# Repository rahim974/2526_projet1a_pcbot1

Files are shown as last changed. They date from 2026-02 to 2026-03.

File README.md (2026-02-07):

# 2526_projet1a_pcbot1
[toc]

## Memo git

Pensez à ajouter votre clé ssh à votre compte github.

### Récupérer le projet

```bash
git clone git@github.com:rahim974/2526_projet1a_pcbot1.git
```

### Récupérer la dernière version

```bash
git pull
```

### Vérifier vos modifications

```bash
git status
```

### Pousser vos modifications

```bash
git add .   # À la place du ".", on peut mettre le chemin des fichiers à ajouter
git commit -m "Message (pour indiquer la mise à jour faite)"
git push
```

# 2/02/2026

## Rôle du robot 

Le robot donne ses coordonnées et ce qu'il y a devant lui (distances aux obstacles). Il doit envoyer son angle d'inclinaison, sa vitesse, son accélération, sa position, à une base.

## Cahier des charges

- Robot doit rouler 
- Connaitre son environnement (distances aux obstacles) 
- Connaitre sa vitesse et sa position
- Pouvoir le charger à une prise 
- Communiquer en continu via le module nrF24L01
- Communiquer avec une station de base (angle, distance)

## Matériels

- Capteur TOF (repérer ce qu'il y a devant)
- nRF24N https://passionelectronique.fr/tutorial-nrf24l01/
- Batterie 18650 Samsung (en USB) https://www.nkon.nl/fr/samsung-inr18650-35e-3400mah-8a.html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
- Moteur continue https://www.gotronic.fr/art-motoreducteur-maqueen-v5-48529.htm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
- Leds 
- Bouton d'alimentation
- Prise secteur https://www.ti.com/lit/ds/symlink/bq25896.pdf?ts=1769962316849
- accéléromètre https://www.st.com/en/mems-and-sensors/lsm6dsox.html
- drivers moteur https://www.ti.com/lit/ds/symlink/drv8411a.pdf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
Ne pas utiliser des librairies déjà existantes sauf si très ressemblant.

## Rôles 

- Schéma architectural sur draw.io 
- Essais capteur TOF

Essais capteur TOF 

I2C entre moteur et accélérateur, driver de batterie

Outil : draw.io

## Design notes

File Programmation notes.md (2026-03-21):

# Fonctionnalités à coder

### 1. Communication et Capteurs (I2C)

- **Driver Capteur TOF (Distance) :** Implémenter le protocole I2C pour lire les distances et repérer les obstacles devant le robot.
- **Driver Accéléromètre (LSM6DSOX) :** Configurer les registres pour récupérer l'accélération et l'inclinaison (angle) afin de connaître la position du robot.
- **Gestion de la Batterie (BQ25896) :** Lire l'état de charge de la batterie Samsung 18650 via I2C pour savoir quand retourner à la prise.

### 2. Propulsion et Mouvement (PWM)

- **Contrôle du DRV8411A :** Générer des signaux PWM pour contrôler la vitesse des moteurs à courant continu.
- **Logique de Direction :** Coder les fonctions de base : `avancer()`, `reculer()`, `tourner_gauche()`, `tourner_droite()` et `stop()`.

### 3. Communication Radio (SPI)

- **Driver nRF24L01 :** Configurer l'interface SPI pour envoyer et recevoir des données en continu.
- **Protocole Station de Base :** Créer une structure de message pour envoyer les coordonnées (angle, distance) à la station de base.

### 4. Interface et Feedback

- **Gestion des LEDs :** Coder les états visuels (ex: clignotement en cas de batterie faible ou obstacle proche).
- **Lecture du Bouton :** Gérer l'anti-rebond (debouncing) pour le bouton d'alimentation ou de démarrage.

### 5. Algorithme Principal (Boucle de contrôle)

- **Évitement d'obstacles :** Fusionner les données du TOF et des moteurs pour s'arrêter avant une collision.
- **Calcul de position :** Utiliser les données de l'accéléromètre pour estimer le déplacement du robot.

# Fonctions déjà existantes à utiliser 

## 1. Pour les Moteurs (Timer & PWM)

Le fichier de référence est `stm32g4xx_hal_tim.h`.

- **`HAL_TIM_PWM_Start(&htimx, TIM_CHANNEL_y)`** :
  - **Rôle** : Allume physiquement le signal PWM sur la broche du moteur.
  - **Utilisation** : À appeler une seule fois dans l'initialisation pour chaque moteur.
- **`__HAL_TIM_SET_COMPARE(&htimx, TIM_CHANNEL_y, valeur)`** :
  - **Rôle** : C'est la fonction la plus importante. Elle change la **vitesse** en modifiant le registre de comparaison (CCR).
  - **Note** : Ce n'est pas une fonction classique mais une "macro" ultra-rapide.

## 2. Pour les Capteurs (I2C)

Le fichier de référence est `stm32g4xx_hal_i2c.h`. Pour ton capteur TOF et le LSM6DSOX, on utilise souvent le mode "Mem" (Mémoire) car ces capteurs fonctionnent avec des registres internes.

- **`HAL_I2C_Mem_Write(...)`** :
  - **Rôle** : Écrit une configuration dans le capteur (ex: allumer le laser du TOF).
- **`HAL_I2C_Mem_Read(...)`** :
  - **Rôle** : Lit une donnée précise (ex: lire les 2 octets de la distance mesurée).

| **Paramètre** | **Signification** | **Exemple (LSM6DSOX)** |
| --- | --- | --- |
| `&hi2c1` | Le bus utilisé | I2C numéro 1 |
| `DevAddress`  | Adresse du composant | `0x6B << 1` (Toujours décaler d'un bit) |
| `MemAddress`  | Registre interne | `0x22` (Donnée Gyro) |
| `pData` | Variable de stockage | Tableau d'octets |

## 3. Pour la Radio nRF24L01 (SPI)

Le fichier de référence est `stm32g4xx_hal_spi.h`.

- **`HAL_SPI_Transmit(&hspix, pData, Size, Timeout)`** :
  - **Rôle** : Envoie un paquet de données vers la station de base via le module radio.
- **`HAL_GPIO_WritePin(GPIOx, GPIO_Pin, PinState)`** :
  - **Rôle** : Très important pour le SPI ! Sert à activer/désactiver la broche **CSN** (Chip Select) pour dire au nRF24 "je te parle à toi".

# 1 ) Initialisation des Moteurs

```c
// Activation des PWM pour le moteur Gauche (ex: TIM1 et TIM2)
HAL_TIM_PWM_Start(&htim1, TIM_CHANNEL_1); 
HAL_TIM_PWM_Start(&htim2, TIM_CHANNEL_1); 

// Activation des PWM pour le moteur Droit (ex: TIM3 et TIM4)
HAL_TIM_PWM_Start(&htim3, TIM_CHANNEL_1); 
HAL_TIM_PWM_Start(&htim4, TIM_CHANNEL_1);
```

# 2) Avancer, Reculer et Pivoter

#### Avancer tout droit

```c
void robot_avancer(uint16_t vitesse) {
    // Moteur Gauche : TIM1 actif, TIM2 à l'arrêt
    __HAL_TIM_SET_COMPARE(&htim1, TIM_CHANNEL_1, vitesse);
    __HAL_TIM_SET_COMPARE(&htim2, TIM_CHANNEL_1, 0);

    // Moteur Droit : TIM3 actif, TIM4 à l'arrêt
    __HAL_TIM_SET_COMPARE(&htim3, TIM_CHANNEL_1, vitesse);
    __HAL_TIM_SET_COMPARE(&htim4, TIM_CHANNEL_1, 0);
}
```

#### Pivoter sur place (Rotation)

```c
void robot_pivoter_gauche(uint16_t vitesse) {
    // Roue Gauche recule
    __HAL_TIM_SET_COMPARE(&htim1, TIM_CHANNEL_1, 0);
    __HAL_TIM_SET_COMPARE(&htim2, TIM_CHANNEL_1, vitesse);

    // Roue Droite avance
    __HAL_TIM_SET_COMPARE(&htim3, TIM_CHANNEL_1, vitesse);
    __HAL_TIM_SET_COMPARE(&htim4, TIM_CHANNEL_1, 0);
}
```

# 3) Boucle principale

```c
while (1) {
    uint16_t distance;
    // Lecture via I2C (fonction simplifiée pour l'exemple)
    distance = TOF_GetDistance(); 

    if (distance > 200) {
        robot_avancer(500); // On roule à 50%
    } else {
        robot_pivoter_gauche(400); // On tourne pour éviter le mur
        HAL_Delay(500); // Petit délai pour effectuer la rotation
    }
    
    // Envoi de la télémétrie vers la station de base via nRF24L01
    NRF24_SendData(distance);
}
```

# 4) Fonction GetDistance()

```c
#define TOF_ADDR (0x29 << 1)  // Adresse par défaut du VL53L0X décalée pour la HAL
#define RESULT_RANGE_STATUS 0x14 // Registre où se trouve la distance

uint16_t TOF_GetDistance(void) {
    uint8_t data[2];
    uint16_t distance = 0;

    // On lit 2 octets à partir du registre 0x14
    // &hi2c1 est la structure générée par CubeIDE pour ton bus I2C
    HAL_StatusTypeDef status = HAL_I2C_Mem_Read(&hi2c1, TOF_ADDR, RESULT_RANGE_STATUS,I2C_MEMADD_SIZE_8BIT, data, 2, 100);

    if (status == HAL_OK) {
        // Le TOF renvoie [MSB, LSB]. On les assemble.
        distance = (data[0] << 8) | data[1];
    } else {
        // Gestion d'erreur (optionnel : retourner une valeur spécifique)
        distance = 8190; // Valeur "hors de portée" par défaut
    }

    return distance;
}
```

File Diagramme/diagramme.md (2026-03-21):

# Diagramme + Bus I2C et Bus SPI

```mermaid
graph LR
    MCU[STM32G431]
    
    subgraph BUS_I2C [Labels: SDA / SCL]
        TOF[Capteur TOF]
        IMU[Accéléromètre LSM6DSOX]
        BQ[Chargeur BQ25896]
    end

    subgraph BUS_SPI [Labels: SCK / MISO / MOSI]
        NRF[nRF24L01]
    end

    subgraph POWER [Labels: VCC / GND]
        BAT[Batterie 18650]
        USB[Prise Secteur/USB]
    end

    subgraph MOTORS [Labels: PWM]
        DRV[Driver DRV8411A]
        M1[Moteurs CC]
    end

    MCU -- "I2C" --- BUS_I2C
    MCU -- "SPI" --- BUS_SPI
    MCU -- "PWM (Vitesse)" --- DRV
    DRV --- M1
    
    USB -- "Charge" --- BQ
    BAT -- "Energie" --- BQ
    BQ -- "Alimentation" --- MCU

    NRF -. "Radio" .-> Station[Station de Base]
    
```

#### BUS I2C :

https://www.yoctopuce.com/FR/article/petite-introduction-au-bus-i2c

https://youtu.be/15XY4LoQyjc?si=3IJ6fjEveq3ZDlDo

#### BUS SPI :

https://lycrouv-sn.fr/rsc/TdTp/Td/ciel2/Datalink/res/bus_spi.pdf

https://youtu.be/2hnIKzI6yYE?si=DDTpKShhfTgUhP8

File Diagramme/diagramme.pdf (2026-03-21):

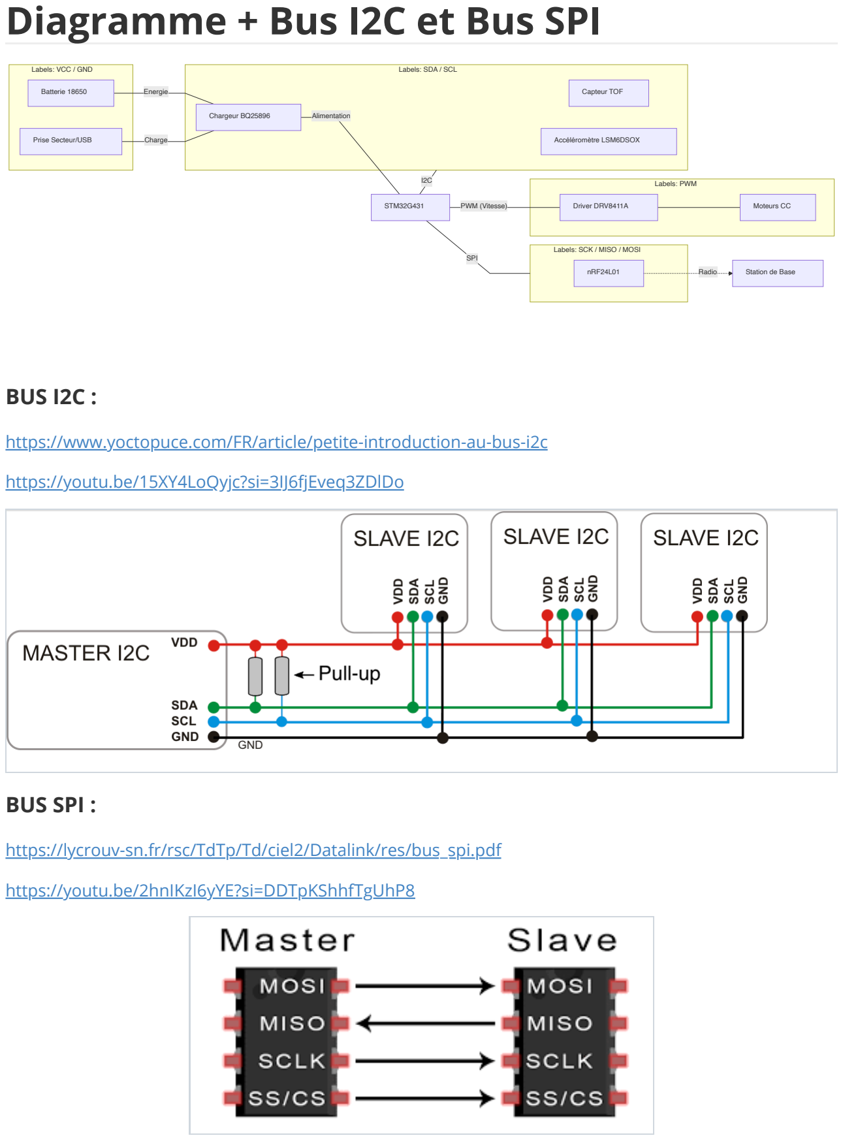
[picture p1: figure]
Labels: PWM; Labels: VCC / GND; Labels: SCK / MISO / MOSI; Labels: SDA / SCL; PWM (Vitesse); Charge; Energie; Alimentation; Radio; SPI; STM32G431; Capteur TOF; Accéléromètre LSM6DSOX; Chargeur BQ25896; nRF24L01; Batterie 18650; Prise Secteur/USB; Driver DRV8411A; Moteurs CC; Station de Base; Diagramme + Bus I2C et Bus SPI; BUS I2C :; BUS SPI :

# https://www.yoctopuce.com/FR/article/petite-introduction-au-bus-i2c

# https://youtu.be/15XY4LoQyjc?si=3IJ6fjEveq3ZDlDo

# https://lycrouv-sn.fr/rsc/TdTp/Td/ciel2/Datalink/res/bus_spi.pdf

# https://youtu.be/2hnIKzI6yYE?si=DDTpKShhfTgUhP8

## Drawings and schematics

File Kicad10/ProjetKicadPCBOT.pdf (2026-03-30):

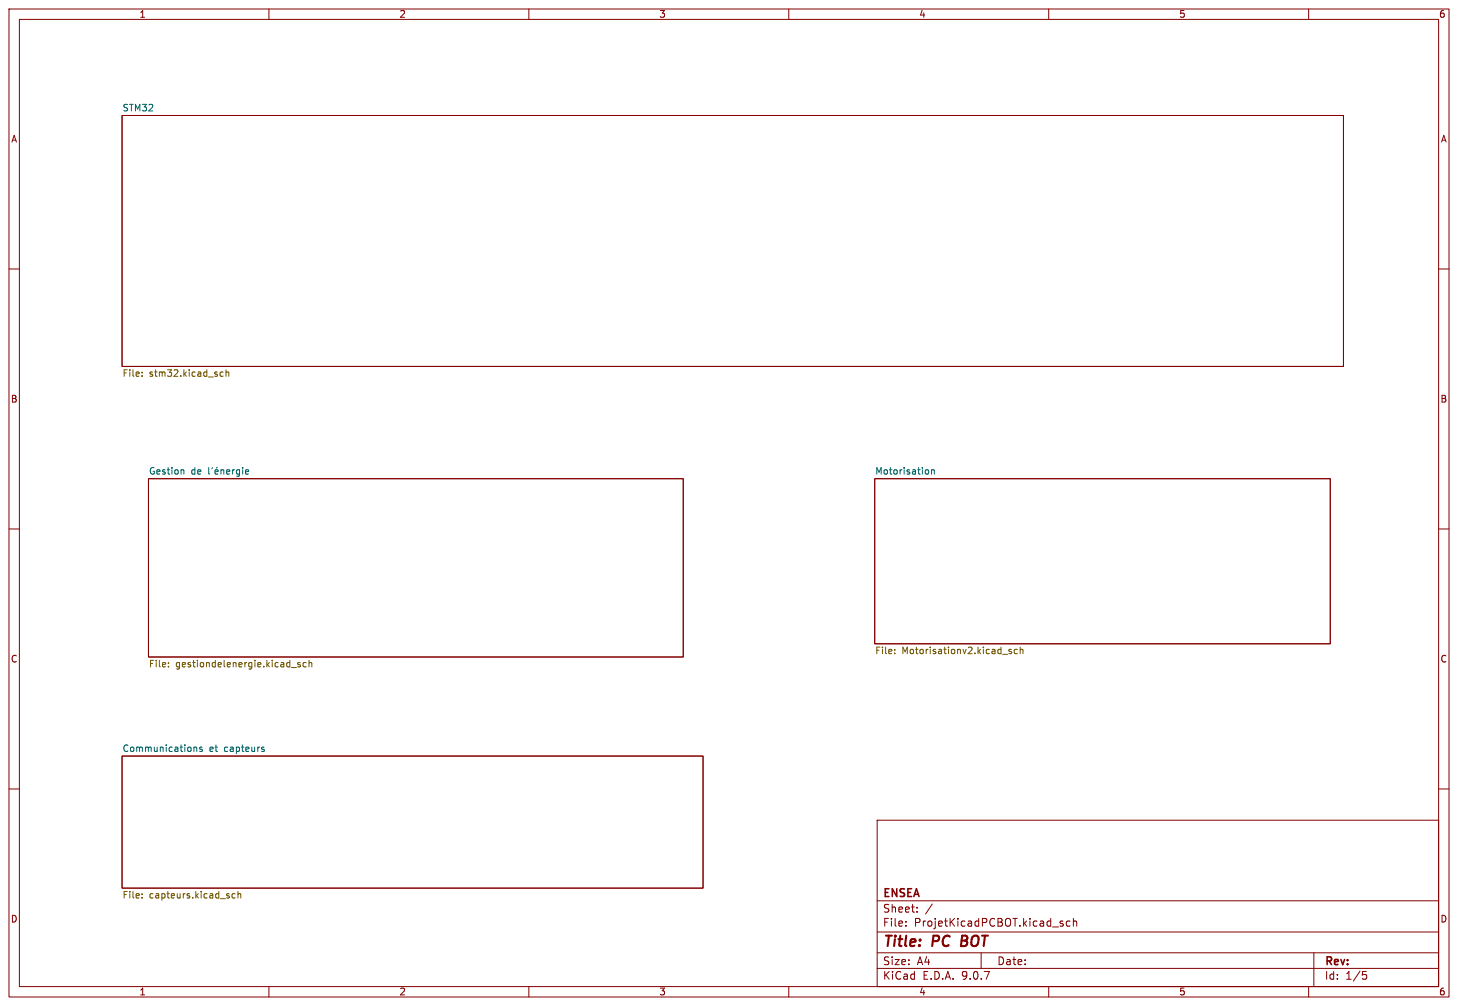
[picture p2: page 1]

File: ProjetKicadPCBOT.kicad_sch Sheet: / ENSEA

Id: 1/5 Title: PC BOT

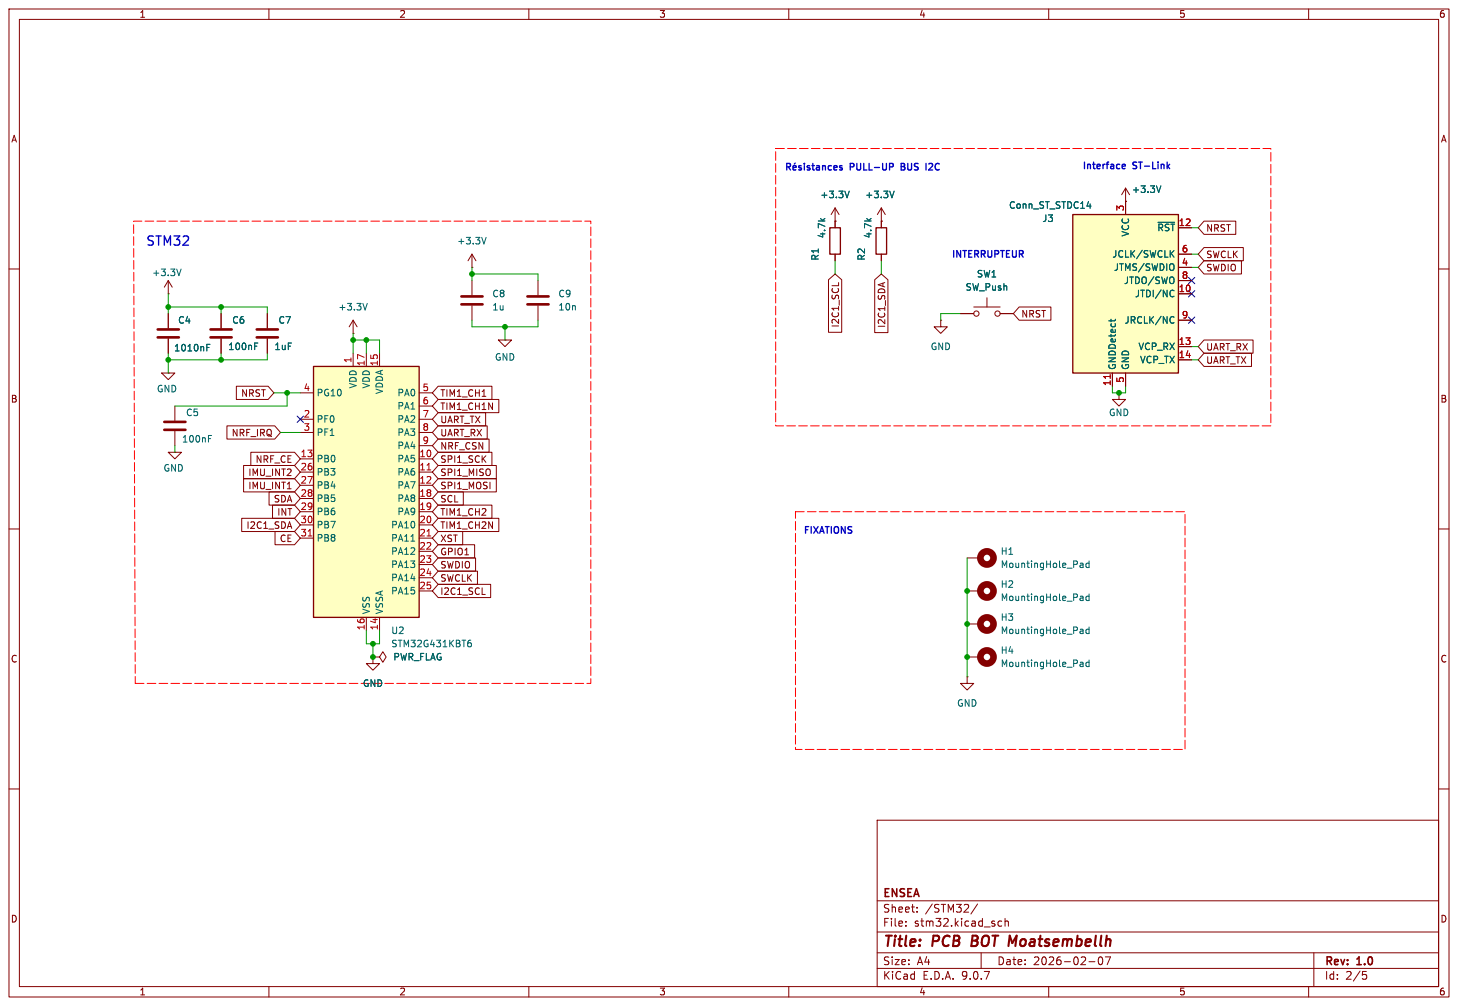
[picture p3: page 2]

1 VDD 17 VSS 16 VDDA 15 VSSA 14 PA0 5 PA1 6 PA2 7 PA3 8 PA4 9 PA5 10 PA6 11 PA7 12 PA8 18 PA9 19 PA10 20 PA11 21 PA12 22 PA13 23 PA14 24 PA15 25 U2STM32G431KBT6 PWR_FLAG

Id: 2/5 Title: PCB BOT Moatsembellh

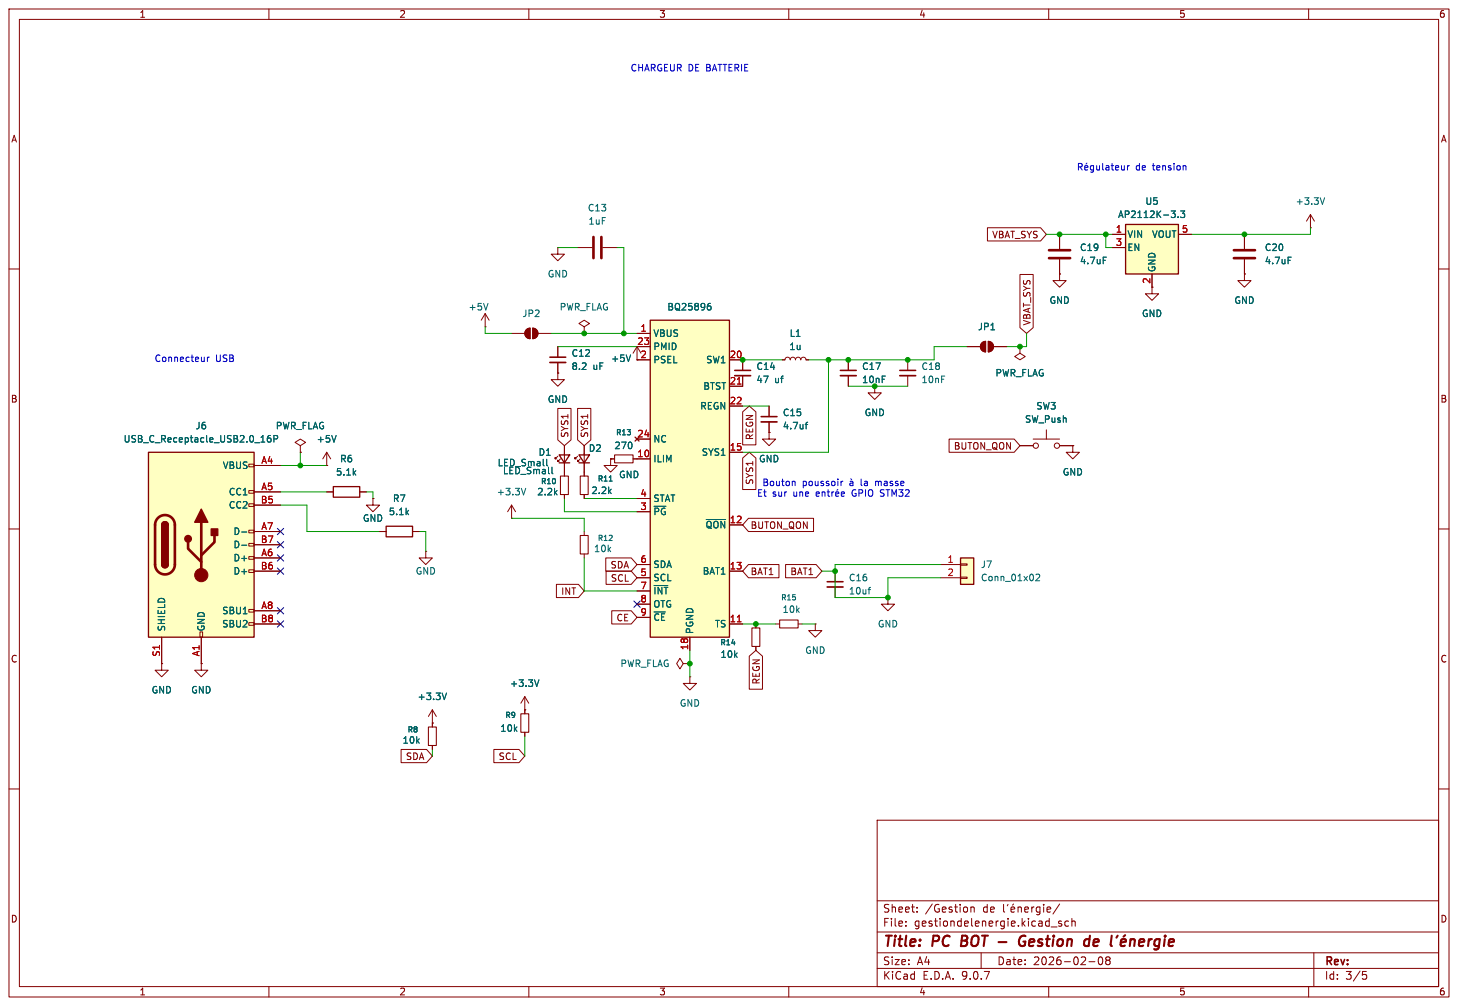
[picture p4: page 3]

Id: 3/5 Title: PC BOT - Gestion de þÿl'énergie

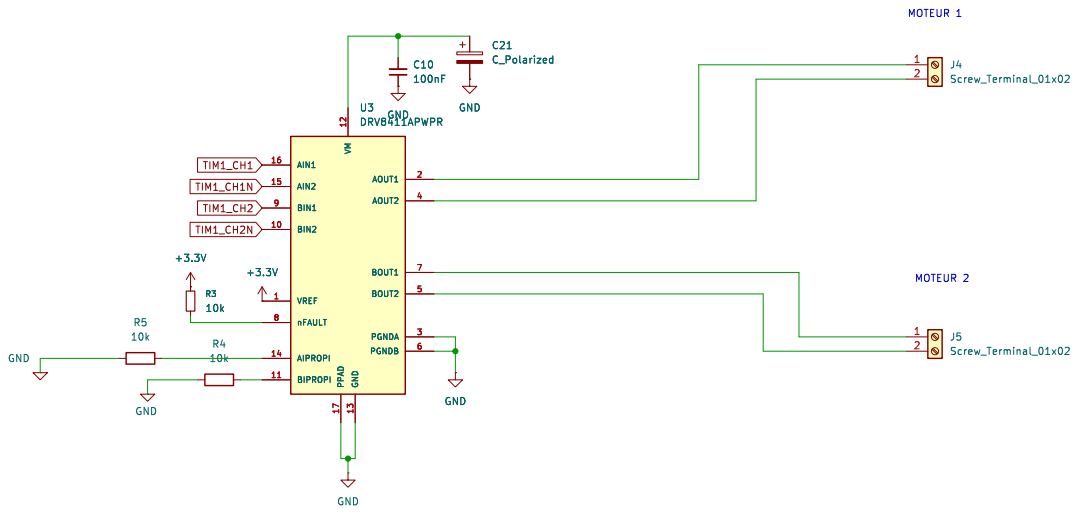
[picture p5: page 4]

Id: 4/5 Title: File: Motorisationv2.kicad_sch Sheet: /Motorisation/ GND

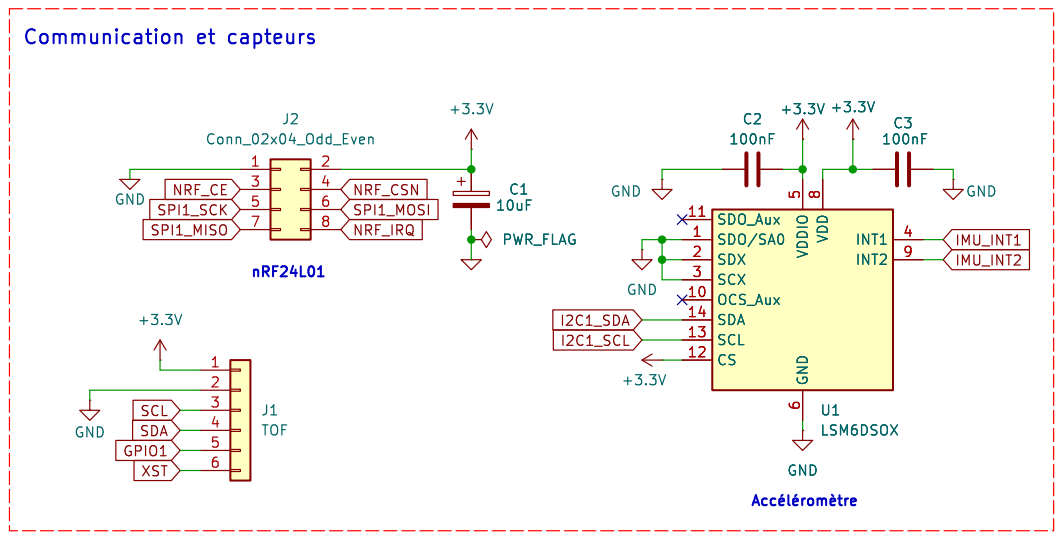
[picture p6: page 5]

IMU_INT1 SPI1_MOSI SDA Communication et capteurs
SPI1_SCK NRF_CE GPIO1 XST SCLSPI1_MISO
J1TOF GND GND

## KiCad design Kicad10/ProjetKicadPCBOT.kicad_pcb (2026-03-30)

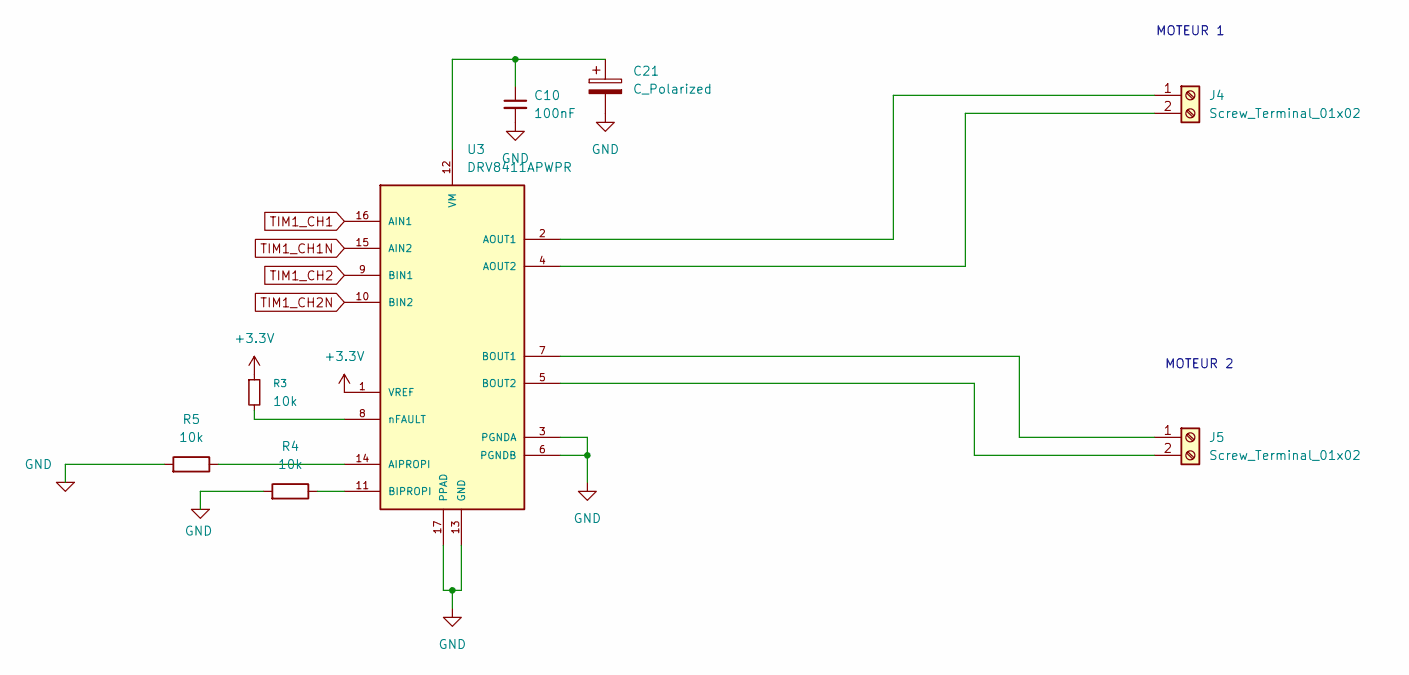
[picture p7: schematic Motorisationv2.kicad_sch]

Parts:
C10: 100nF; C_0603_1608Metric_Pad1.08x0.95mm_HandSolder
C21: C_Polarized; CP_Elec_6.3x3
J4, J5: Screw_Terminal_01x02; TerminalBlock_Phoenix_MKDS-1,5-2-5.08_1x02_P5.08mm_Horizont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
R3, R4, R5: 10k; R_0805_2012Metric_Pad1.20x1.40mm_HandSolder
U3: DRV8411APWPR; HTSSOP-16-1EP_4.4x5mm_P0.65mm_EP3.4x5mm_Mask3x3mm_ThermalVi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; PARTREV A; DigiKey_Part_Number 296-DRV8411APWPRCT-ND

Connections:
+3.3V: R3.1, U3.1 (VREF); also elsewhere on the board
GND: C10.2, C21.2, R4.2, R5.2, U3.3 (PGNDA), U3.6 (PGNDB), U3.13 (GND), U3.17 (PPAD); also elsewhere on the board
unnamed: J4.1, U3.2 (AOUT1)
unnamed: J4.2, U3.4 (AOUT2)
unnamed: J5.1, U3.7 (BOUT1)
unnamed: J5.2, U3.5 (BOUT2)
unnamed: R5.1, U3.14 (AIPROPI)
unnamed: R4.1, U3.11 (BIPROPI)
unnamed: C10.1, C21.1, U3.12 (VM)
unnamed: R3.2, U3.8 (nFAULT)
TIM1_CH1: U3.16 (AIN1); also elsewhere on the board
TIM1_CH1N: U3.15 (AIN2); also elsewhere on the board
TIM1_CH2: U3.9 (BIN1); also elsewhere on the board
TIM1_CH2N: U3.10 (BIN2); also elsewhere on the board

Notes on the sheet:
MOTEUR 1
MOTEUR 2

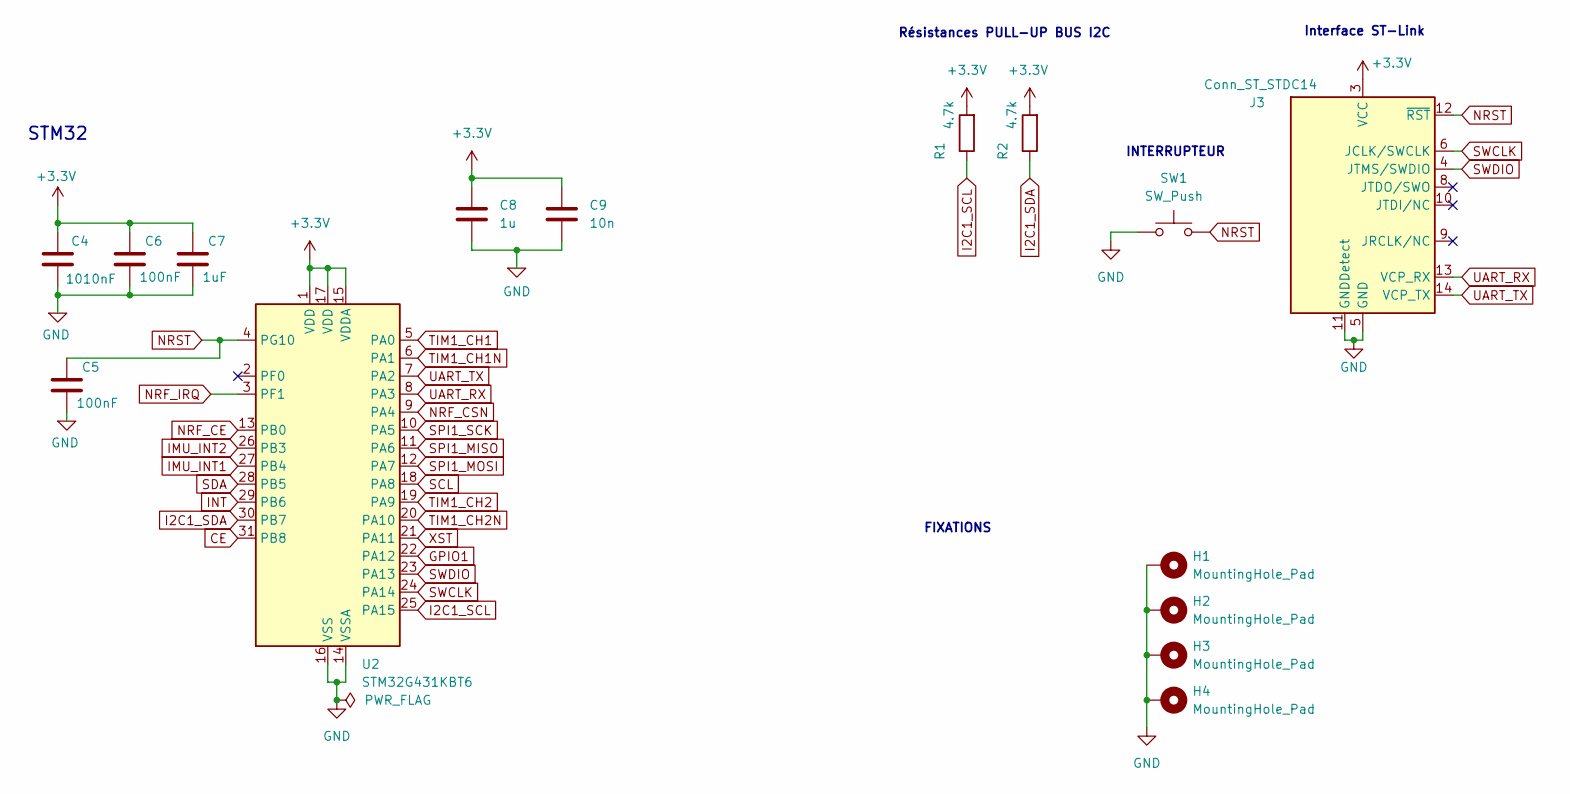
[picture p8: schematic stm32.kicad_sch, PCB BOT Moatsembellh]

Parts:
C4: 1010nF; C_0603_1608Metric_Pad1.08x0.95mm_HandSolder
C5, C6: 100nF; C_0603_1608Metric_Pad1.08x0.95mm_HandSolder
C7: 1uF; C_0603_1608Metric_Pad1.08x0.95mm_HandSolder
C8: 1u; C_0603_1608Metric_Pad1.08x0.95mm_HandSolder
C9: 10n; C_0603_1608Metric_Pad1.08x0.95mm_HandSolder
H1, H2, H3, H4: MountingHole_Pad; MountingHole_3.2mm_M3_DIN965_Pad
J3: Conn_ST_STDC14; PinHeader_2x07_P1.27mm_Vertical_SMD
R1, R2: 4.7k; R_0805_2012Metric_Pad1.20x1.40mm_HandSolder
SW1: SW_Push; SW_Push_1P1T_NO_E-Switch_TL3301NxxxxxG
U2: STM32G431KBT6; LQFP-32_7x7mm_P0.8mm

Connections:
+3.3V: C4.1, C6.1, C7.1, C8.2, C9.2, J3.3 (VCC), R1.2, R2.2, U2.1 (VDD), U2.15 (VDDA), U2.17 (VDD); also elsewhere on the board
CE: U2.31 (PB8); also elsewhere on the board
GND: C4.2, C5.2, C6.2, C7.2, C8.1, C9.1, H1.1, H2.1, H3.1, H4.1, J3.5 (GND), J3.7 (GND), J3.11 (GNDDetect), SW1.1, U2.14 (VSSA), U2.16 (VSS), U2.32 (VSS); also elsewhere on the board
GPIO1: U2.22 (PA12); also elsewhere on the board
I2C1_SCL: R1.1, U2.25 (PA15); also elsewhere on the board
I2C1_SDA: R2.1, U2.30 (PB7); also elsewhere on the board
IMU_INT1: U2.27 (PB4); also elsewhere on the board
IMU_INT2: U2.26 (PB3); also elsewhere on the board
INT: U2.29 (PB6); also elsewhere on the board
NRF_CE: U2.13 (PB0); also elsewhere on the board
NRF_CSN: U2.9 (PA4); also elsewhere on the board
NRF_IRQ: U2.3 (PF1); also elsewhere on the board
NRST: C5.1, J3.12 (~RST), SW1.2, U2.4 (PG10)
SCL: U2.18 (PA8); also elsewhere on the board
SDA: U2.28 (PB5); also elsewhere on the board
SPI1_MISO: U2.11 (PA6); also elsewhere on the board
SPI1_MOSI: U2.12 (PA7); also elsewhere on the board
SPI1_SCK: U2.10 (PA5); also elsewhere on the board
SWCLK: J3.6 (JCLK/SWCLK), U2.24 (PA14)
SWDIO: J3.4 (JTMS/SWDIO), U2.23 (PA13)
TIM1_CH1: U2.5 (PA0); also elsewhere on the board
TIM1_CH1N: U2.6 (PA1); also elsewhere on the board
TIM1_CH2: U2.19 (PA9); also elsewhere on the board
TIM1_CH2N: U2.20 (PA10); also elsewhere on the board
UART_RX: J3.13 (VCP_RX), U2.8 (PA3)
UART_TX: J3.14 (VCP_TX), U2.7 (PA2)
XST: U2.21 (PA11); also elsewhere on the board

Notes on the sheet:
FIXATIONS
Résistances PULL-UP BUS I2C
STM32
Interface ST-Link
INTERRUPTEUR

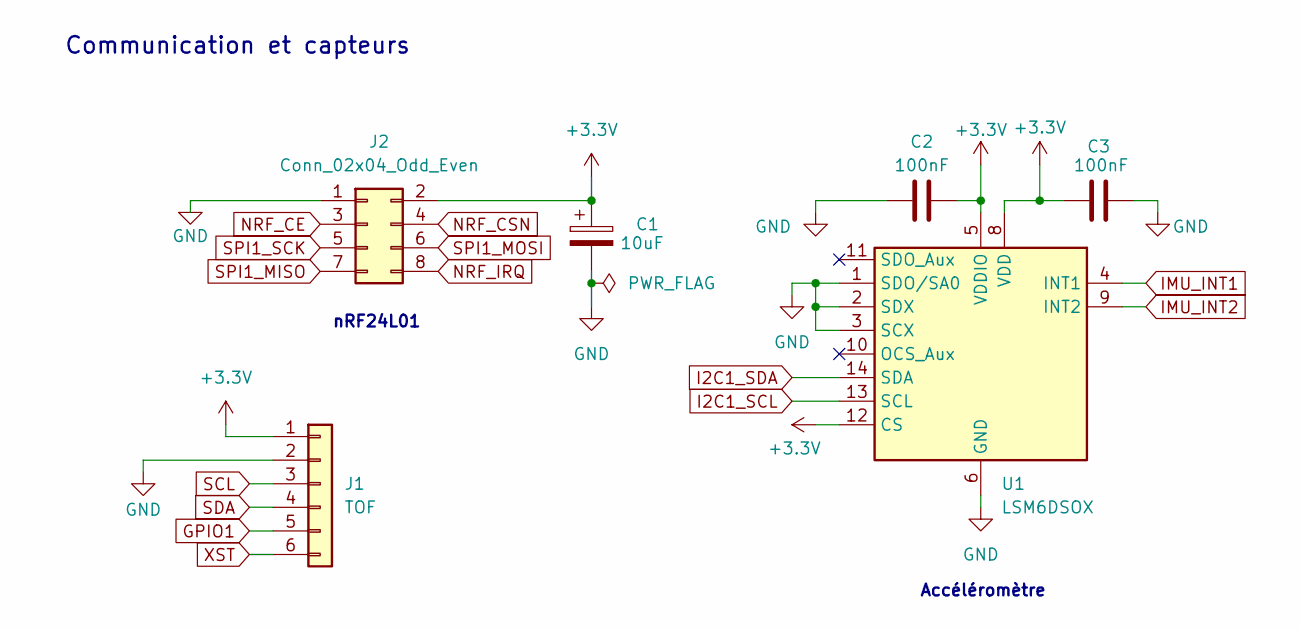
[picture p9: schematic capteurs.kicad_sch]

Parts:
C1: 10uF; C_0603_1608Metric_Pad1.08x0.95mm_HandSolder
C2, C3: 100nF; C_0603_1608Metric_Pad1.08x0.95mm_HandSolder
J1: TOF; PinHeader_1x06_P2.54mm_Vertical
J2: Conn_02x04_Odd_Even; PinSocket_2x04_P2.54mm_Vertical
U1: LSM6DSOX; LGA-14_3x2.5mm_P0.5mm_LayoutBorder3x4y

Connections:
+3.3V: C1.1, C2.2, C3.1, J1.1, J2.2, U1.5 (VDDIO), U1.8 (VDD), U1.12 (CS); also elsewhere on the board
GND: C1.2, C2.1, C3.2, J1.2, J2.1, U1.1 (SDO/SA0), U1.2 (SDX), U1.3 (SCX), U1.6 (GND), U1.7 (GND); also elsewhere on the board
GPIO1: J1.5; also elsewhere on the board
I2C1_SCL: U1.13 (SCL); also elsewhere on the board
I2C1_SDA: U1.14 (SDA); also elsewhere on the board
IMU_INT1: U1.4 (INT1); also elsewhere on the board
IMU_INT2: U1.9 (INT2); also elsewhere on the board
NRF_CE: J2.3; also elsewhere on the board
NRF_CSN: J2.4; also elsewhere on the board
NRF_IRQ: J2.8; also elsewhere on the board
SCL: J1.3; also elsewhere on the board
SDA: J1.4; also elsewhere on the board
SPI1_MISO: J2.7; also elsewhere on the board
SPI1_MOSI: J2.6; also elsewhere on the board
SPI1_SCK: J2.5; also elsewhere on the board
XST: J1.6; also elsewhere on the board

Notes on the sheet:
Accéléromètre
Communication et capteurs
nRF24L01

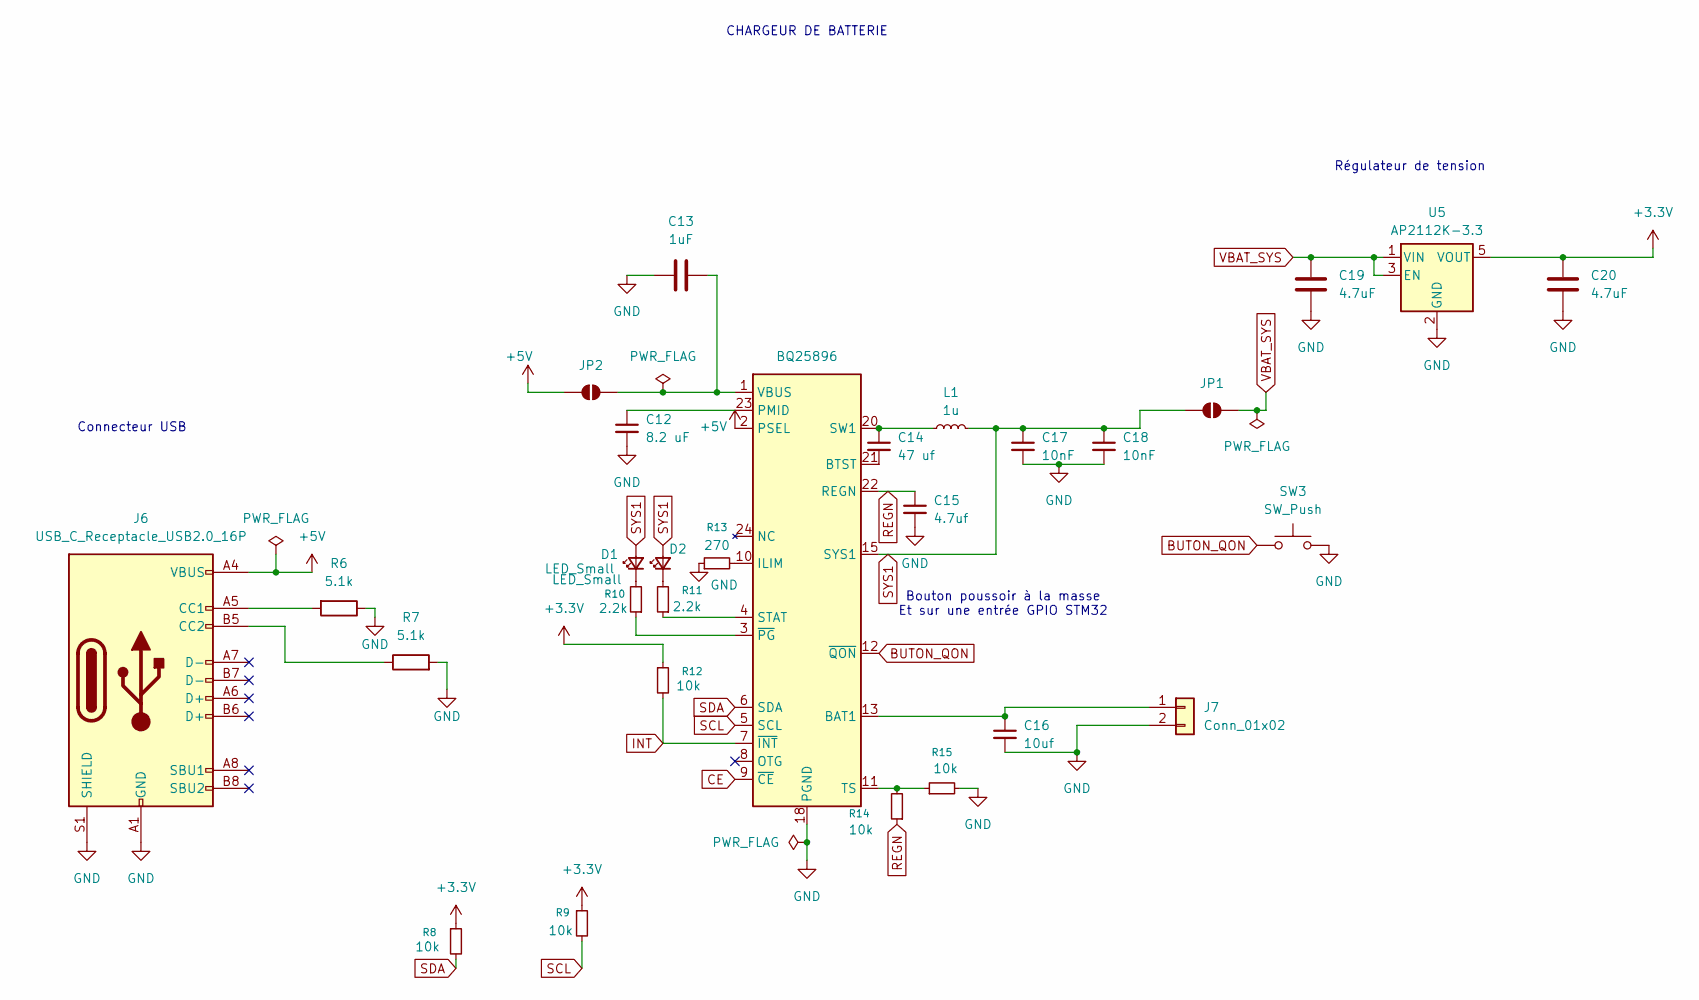
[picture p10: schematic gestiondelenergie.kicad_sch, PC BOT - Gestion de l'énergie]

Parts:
C12: 8.2 uF; C_0603_1608Metric_Pad1.08x0.95mm_HandSolder
C13: 1uF; C_0603_1608Metric_Pad1.08x0.95mm_HandSolder
C14: 47 uf; C_0603_1608Metric_Pad1.08x0.95mm_HandSolder
C15: 4.7uf; C_0603_1608Metric_Pad1.08x0.95mm_HandSolder
C16: 10uf; C_0603_1608Metric_Pad1.08x0.95mm_HandSolder
C17, C18: 10nF; C_0603_1608Metric_Pad1.08x0.95mm_HandSolder
C19, C20: 4.7uF; C_0603_1608Metric_Pad1.08x0.95mm_HandSolder
D1, D2: LED_Small; LED_0603_1608Metric_Pad1.05x0.95mm_HandSolder
J6: USB_C_Receptacle_USB2.0_16P; USB_C_Receptacle_GCT_USB4105-xx-A_16P_TopMnt_Horizontal
J7: Conn_01x02; JST_PH_S2B-PH-K_1x02_P2.00mm_Horizontal
JP1, JP2: SolderJumper_2_Open; SolderJumper-2_P1.3mm_Open_TrianglePad1.0x1.5mm
L1: 1u; L_0805_2012Metric_Pad1.05x1.20mm_HandSolder
R6, R7: 5.1k; R_0805_2012Metric_Pad1.20x1.40mm_HandSolder
R8, R9, R12, R14, R15: 10k; R_0805_2012Metric_Pad1.20x1.40mm_HandSolder
R10, R11: 2.2k; R_0805_2012Metric_Pad1.20x1.40mm_HandSolder
R13: 270; R_0805_2012Metric_Pad1.20x1.40mm_HandSolder
SW3: SW_Push; SW_Push_1P1T_NO_E-Switch_TL3301NxxxxxG
U4: BQ25896; WQFN-24-1EP_4x4mm_P0.5mm_EP2.45x2.45mm_ThermalVias
U5: AP2112K-3.3; SOT-23-5

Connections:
+3.3V: C20.1, R8.1, R9.1, R12.1, U5.5 (VOUT); also elsewhere on the board
+5V: J6.A4 (VBUS), J6.A9 (VBUS), J6.B4 (VBUS), J6.B9 (VBUS), JP2.1 (A), U4.2 (PSEL)
BUTON_QON: SW3.1, U4.12 (~QON)
CE: U4.9 (~CE); also elsewhere on the board
GND: C12.2, C13.1, C15.2, C16.2, C17.2, C18.2, C19.2, C20.2, J6.A1 (GND), J6.A12 (GND), J6.B1 (GND), J6.B12 (GND), J6.S1 (SHIELD), J7.2, R6.1, R7.2, R13.1, R15.2, SW3.2, U4.17 (PGND), U4.18 (PGND), U4.25 (PGND), U5.2 (GND); also elsewhere on the board
INT: R12.2, U4.7 (~INT); also elsewhere on the board
unnamed: D1.1 (K), R10.2
unnamed: D2.1 (K), R11.2
unnamed: J6.A5 (CC1), R6.2
unnamed: J6.B5 (CC2), R7.1
unnamed: C16.1, J7.1, U4.13 (BAT1), U4.14 (BAT2)
unnamed: C14.2, U4.21 (BTST)
unnamed: R13.2, U4.10 (ILIM)
unnamed: C12.1, U4.23 (PMID)
unnamed: R11.1, U4.4 (STAT)
unnamed: C14.1, L1.1, U4.19 (SW2), U4.20 (SW1)
unnamed: R14.2, R15.1, U4.11 (TS)
REGN: C15.1, R14.1, U4.22 (REGN)
SCL: R9.2, U4.5 (SCL); also elsewhere on the board
SDA: R8.2, U4.6 (SDA); also elsewhere on the board
SYS1: C17.1, C18.1, D1.2 (A), D2.2 (A), JP1.1 (A), L1.2, U4.15 (SYS1), U4.16 (SYS2)
VBAT_SYS: C19.1, JP1.2 (B), U5.1 (VIN), U5.3 (EN)

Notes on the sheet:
Connecteur USB
Bouton poussoir à la masse Et sur une entrée GPIO STM32
Régulateur de tension
CHARGEUR DE BATTERIE

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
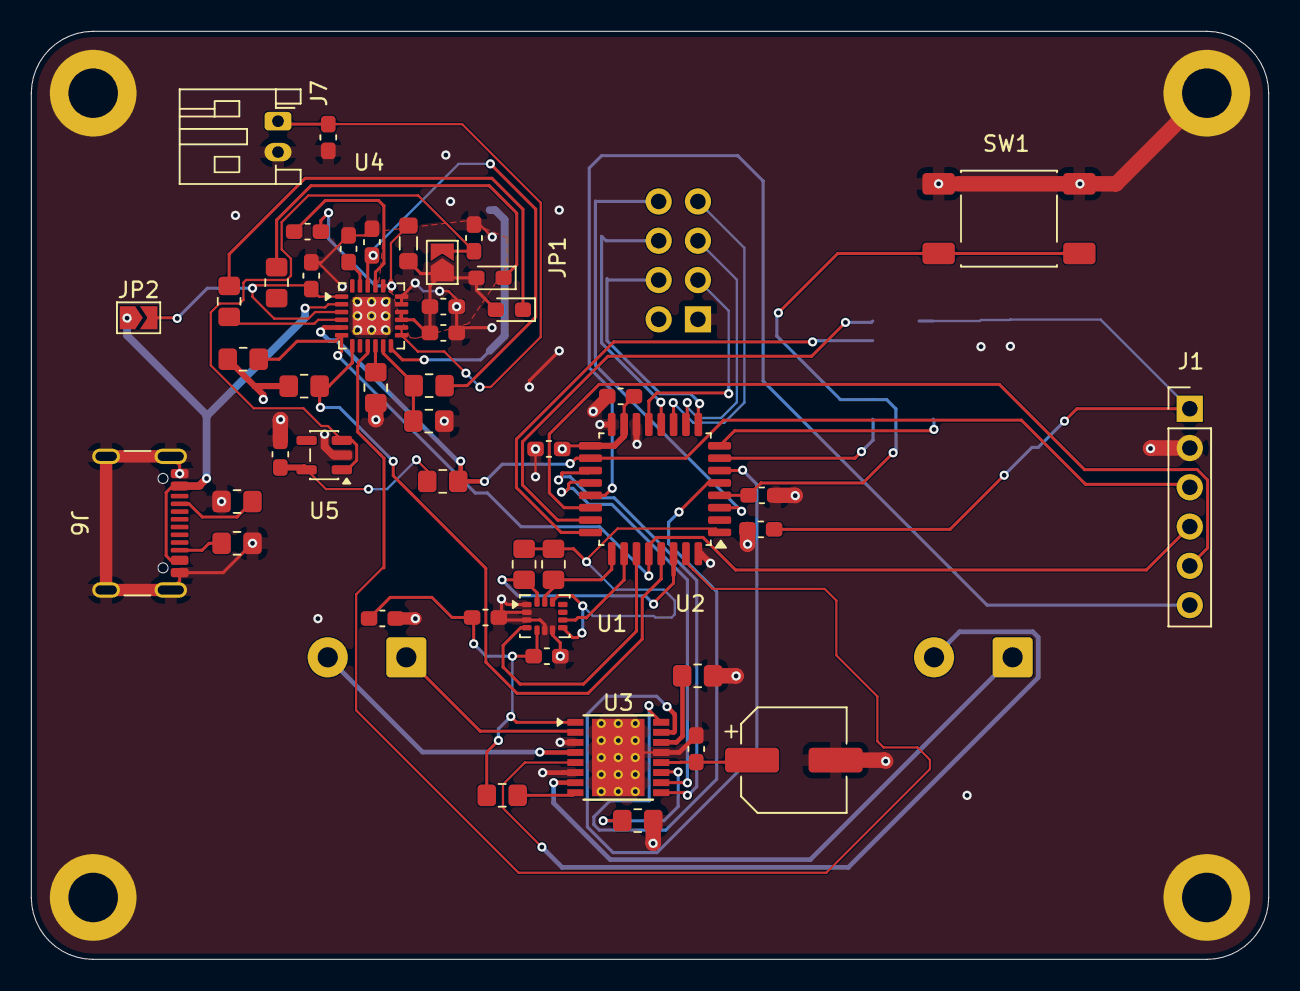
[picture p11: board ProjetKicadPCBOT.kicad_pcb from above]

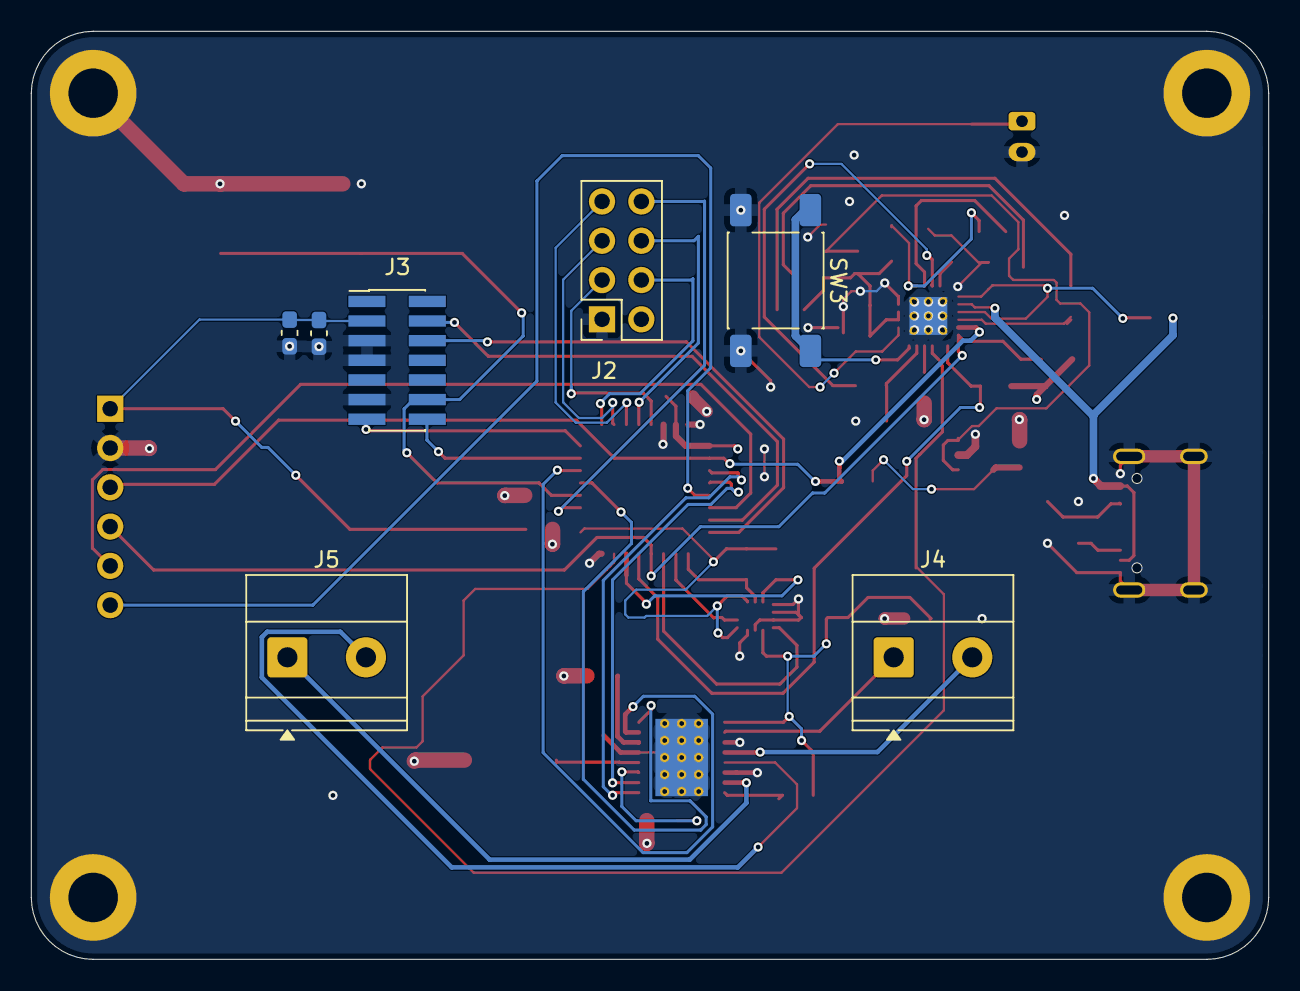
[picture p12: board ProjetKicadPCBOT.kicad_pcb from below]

Board: 4 copper layers, 80.0 x 60.0 mm, 58 parts (7 on the bottom side), 52 nets.

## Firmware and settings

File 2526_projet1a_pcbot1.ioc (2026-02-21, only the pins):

Mcu.UserName=STM32G431KBTx
PA0.Signal=S_TIM2_CH1
PA1.Signal=S_TIM2_CH2
PA10.Signal=S_TIM2_CH4
PA11.GPIO_Label=XST
PA11.Signal=GPIO_Output
PA12.GPIO_Label=GPIO1
PA12.Signal=GPIO_Output
PA13.Signal=SYS_JTMS-SWDIO
PA14.Signal=SYS_JTCK-SWCLK
PA15.Signal=I2C1_SCL
PA2.Signal=USART2_TX
PA3.Signal=USART2_RX
PA4.GPIO_Label=NRF_CSN
PA4.Signal=GPIO_Output
PA5.Signal=SPI1_SCK
PA6.Signal=SPI1_MISO
PA7.Signal=SPI1_MOSI
PA8.Signal=I2C3_SCL
PA9.Signal=S_TIM2_CH3
PB0.GPIO_Label=NRF_CE
PB0.Signal=GPIO_Output
PB3.GPIO_Label=IMU_INT2
PB3.Signal=GPXTI3
PB4.GPIO_Label=IMU_INT1
PB4.Signal=GPXTI4
PB5.Signal=I2C3_SDA
PB6.GPIO_Label=INT
PB6.Signal=GPXTI6
PB7.Signal=I2C1_SDA
PB8-BOOT0.GPIO_Label=CE
PB8-BOOT0.Signal=GPIO_Output
PF1-OSC_OUT.GPIO_Label=NRF_IRQ
PF1-OSC_OUT.Signal=GPXTI1

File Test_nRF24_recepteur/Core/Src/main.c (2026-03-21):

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
/* Includes ------------------------------------------------------------------*/
#include "main.h"

I2C_HandleTypeDef hi2c1;

SPI_HandleTypeDef hspi1;

UART_HandleTypeDef huart2;

void SystemClock_Config(void);
static void MX_GPIO_Init(void);
static void MX_USART2_UART_Init(void);
static void MX_SPI1_Init(void);
static void MX_I2C1_Init(void);
/* USER CODE BEGIN 0 */


int __io_putchar(int ch)
{
	HAL_UART_Transmit(&huart2, (uint8_t *)&ch, 1, HAL_MAX_DELAY);
	return ch;
}



int __io_getchar(void)
{
	uint8_t ch = 0;
	__HAL_UART_CLEAR_OREFLAG(&huart2);
	HAL_UART_Receive(&huart2, (uint8_t *)&ch, 1, HAL_MAX_DELAY);
	HAL_UART_Transmit(&huart2, (uint8_t *)&ch, 1, HAL_MAX_DELAY);
	return ch;
}

void NRF24_WriteRegister(uint8_t reg, uint8_t value) {

uint8_t buf[2];

buf[0] = reg | 0x20;

buf[1] = value;

HAL_GPIO_WritePin(NRF_CSN_GPIO_Port, NRF_CSN_Pin, GPIO_PIN_RESET);

HAL_SPI_Transmit(&hspi1, buf, 2, 100);

HAL_GPIO_WritePin(NRF_CSN_GPIO_Port, NRF_CSN_Pin, GPIO_PIN_SET);

}



void NRF24_SendCommand(uint8_t cmd) {

HAL_GPIO_WritePin(NRF_CSN_GPIO_Port, NRF_CSN_Pin, GPIO_PIN_RESET);

HAL_SPI_Transmit(&hspi1, &cmd, 1, 100);

HAL_GPIO_WritePin(NRF_CSN_GPIO_Port, NRF_CSN_Pin, GPIO_PIN_SET);

}



// Fonction spécifique pour lire le message reçu

void NRF24_ReadPayload(uint8_t *data, uint8_t size) {

uint8_t cmd = 0x61; // Commande "R_RX_PAYLOAD"

HAL_GPIO_WritePin(NRF_CSN_GPIO_Port, NRF_CSN_Pin, GPIO_PIN_RESET);

HAL_SPI_Transmit(&hspi1, &cmd, 1, 100);

HAL_SPI_Receive(&hspi1, data, size, 100);

HAL_GPIO_WritePin(NRF_CSN_GPIO_Port, NRF_CSN_Pin, GPIO_PIN_SET);

}
//******************************CODE test accelerometre ***************************
// 1 .FONCTION DE LECTURE DES ACCELERATIONS
#define LSM6DSOX_ADDR 0x6A << 1
void LSM6DSOX_WriteReg(uint8_t reg, uint8_t data)
{
    HAL_I2C_Mem_Write(&hi2c1, LSM6DSOX_ADDR, reg, 1, &data, 1, 100);
}
void LSM6DSOX_ReadRegs(uint8_t reg, uint8_t *buffer, uint8_t len)
{
    HAL_I2C_Mem_Read(&hi2c1, LSM6DSOX_ADDR, reg, 1, buffer, len, 100);
}
void LSM6DSOX_ReadAccel(int16_t *ax, int16_t *ay, int16_t *az)
{
    uint8_t data[6];
    LSM6DSOX_ReadRegs(0x28, data, 6);
    //lsm6ds0x_read_reg(0x28, data, 6);

    *ax = (int16_t)(data[1] << 8 | data[0]);
    *ay = (int16_t)(data[3] << 8 | data[2]);
    *az = (int16_t)(data[5] << 8 | data[4]);
}




/* USER CODE END 0 */

/**
  * @brief  The application entry point.
  * @retval int
  */
int main(void)
{

  /* MCU Configuration--------------------------------------------------------*/

  /* Reset of all peripherals, Initializes the Flash interface and the Systick. */
  HAL_Init();

  /* Configure the system clock */
  SystemClock_Config();

  /* Initialize all configured peripherals */
  MX_GPIO_Init();
  MX_USART2_UART_Init();
  MX_SPI1_Init();
  MX_I2C1_Init();
  /* USER CODE BEGIN 2 */





//  HAL_GPIO_WritePin(NRF_CE_GPIO_Port, NRF_CE_Pin, GPIO_PIN_RESET);

//  HAL_Delay(10);
  // 2. Initialisation accelerometre
  LSM6DSOX_WriteReg(0x10, 0x40);
  //lsm6ds0x_write_reg(0x10, 0x40);
  int16_t ax, ay, az;
  uint8_t who_am_i;

  HAL_I2C_Mem_Read(&hi2c1, LSM6DSOX_ADDR, 0x0F, 1, &who_am_i, 1, 100);

/*

  // 1. CONFIGURATION RÉCEPTEUR

  NRF24_WriteRegister(0x00, 0x0F); // CONFIG : Power Up, Mode RX (Bit PRIM_RX à 1)

  NRF24_WriteRegister(0x01, 0x01); // EN_AA : Auto-Ack activé sur Pipe 0

  NRF24_WriteRegister(0x11, 5); // RX_PW_P0 : On attend 5 octets (taille de "HELLO")

  // 2. Nettoyage

  NRF24_SendCommand(0xE2); // Flush RX

  NRF24_WriteRegister(0x07, 0x70); // Reset STATUS



  // 3. ACTIVER L'ÉCOUTE

  HAL_GPIO_WritePin(NRF_CE_GPIO_Port, NRF_CE_Pin, GPIO_PIN_SET);

  // En mode RX, CE reste à 1 pour écouter en continu   */
  /* USER CODE END 2 */

  /* Infinite loop */
  /* USER CODE BEGIN WHILE */
/*
  NRF24_WriteRegister(0x00, 0x00); // On éteint
  HAL_Delay(10);
  NRF24_WriteRegister(0x00, 0x0F); // On rallume proprement en mode Récepteur
*/
  while (1)
  {



/*
	  // A. Lire le registre STATUS pour voir si on a reçu quelque chose

	  HAL_GPIO_WritePin(NRF_CSN_GPIO_Port, NRF_CSN_Pin, GPIO_PIN_RESET);

	  uint8_t cmd = 0x07;

	  HAL_SPI_Transmit(&hspi1, &cmd, 1, 10);

	  HAL_SPI_Receive(&hspi1, &status_reg, 1, 10);

	  HAL_GPIO_WritePin(NRF_CSN_GPIO_Port, NRF_CSN_Pin, GPIO_PIN_SET);



	  // B. Vérifier le Bit 6 (RX_DR : Data Ready)

	  if (status_reg & (1 << 6))

	  {

	  // On a reçu un message !

	  NRF24_ReadPayload(rx_data, 5); // Lire les 5 octets

	  // Effacer le drapeau RX_DR pour pouvoir recevoir le prochain message

	  NRF24_WriteRegister(0x07, 0x40);

	  // Optionnel : Envoyer sur le port série pour voir dans la console

	  HAL_UART_Transmit(&huart2, (uint8_t*)"Recu: ", 6, 10);

	  HAL_UART_Transmit(&huart2, rx_data, 5, 10);

	  HAL_UART_Transmit(&huart2, (uint8_t*)"\r\n", 2, 10);

	  }



	  HAL_Delay(100); // On vérifie toutes les 100ms
	  */
	  // CODE ACCELEROMETRE
	  if(who_am_i == 0x6C)
	      {
	          printf("Capteur OK\n");
	      }
	      else
	      {
	          printf("Erreur capteur\n");
	      }

	      HAL_Delay(1000);
	  LSM6DSOX_ReadAccel(&ax, &ay, &az);

	  float ax_g = ax * 0.000061;
	  float ay_g = ay * 0.000061;
	  float az_g = az * 0.000061;


    /* USER CODE END WHILE */

    /* USER CODE BEGIN 3 */
  }
  /* USER CODE END 3 */
}

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


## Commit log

2026-02-02 Message (pour indiquer la mise à jour faite)
2026-02-16 proj kicad update la team
    [Motorisationv2.kicad_sch, PC BOT.kicad_pcb, PC BOT.kicad_sch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]
2026-02-21 Fichier ioc pour programmer la STM32
2026-02-21 Fichier ioc pour la programmation sur STM23CubeIDE
2026-02-21 PCB BOT LE VRAI corrigé
    Pour correspondre au fichier ioc
    [Motorisationv2.kicad_sch, gestiondelenergie.kicad_sch, racine.kicad_sch]
2026-03-02 Maj projet kicad
    Assignation des empreintes et restructuration du shematic
    [Motorisationv2.kicad_sch, ProjetKicadPCBOT.kicad_pcb, ProjetKicadPCBOT.kicad_sch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]
2026-03-30 Projet Kicad
    [Motorisationv2.kicad_sch, ProjetKicadPCBOT.dsn, ProjetKicadPCBOT.kicad_pcb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]
2026-03-30 Add files via upload
    j'ai supprimer les noms des petits composants
    [Motorisationv2.kicad_sch, ProjetKicadPCBOT.dsn, ProjetKicadPCBOT.kicad_pcb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]
2026-03-30 Il reste 6 warning et il faut arranger les écritures
    [Motorisationv2.kicad_sch, ProjetKicadPCBOT.kicad_pcb, ProjetKicadPCBOT.kicad_sch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]
2026-03-30 Add files via upload
    dsl les gars jsp pk mais je n'arrive pas à telecharger les anciennes version sur kicad 9
    [Motorisationv2.kicad_sch, ProjetKicadPCBOT.dsn, ProjetKicadPCBOT.kicad_pcb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]
2026-04-13 Ajout final de la sérigraphie
2026-04-13 Regenerate Gerber files and add drill report
2026-04-13 Add backups and gerber; update active layer
2026-05-11 Update KiCad PCB et readme
2026-05-29 Codes NRF
    Codes pour faire fonctionner les capteurs nrf

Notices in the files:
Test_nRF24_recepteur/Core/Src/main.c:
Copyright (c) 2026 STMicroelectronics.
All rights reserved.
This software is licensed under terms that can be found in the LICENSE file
